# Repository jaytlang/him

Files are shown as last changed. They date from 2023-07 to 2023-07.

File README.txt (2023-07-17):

==========
    he
==========

https://youtu.be/btHpHjabRcc

tour of the stuffs:
- cad: physical lamp design, self explanatory
- embed: source code for ESP32 (little chip friend)
- emulate: emulated LEDs to test WS2812s
- esp-idf and esp-protocols: firmware for ESP32
- web: wifi authentication portal html files (ewgh) (symlink into embed/)

to build the software in embed / reprogram the ESP:
- grab this repository: `git clone --recursive https://github.com/jaytlang/him`
- install python if you haven't yet...
- install esp-idf by opening up the command prompt, changing to the esp-idf
  subdirectory in this folder, and running install.bat. guessing you change
  directories with `cd` in the command prompt.
- activate esp-idf by running export.bat in this same folder
- navigate to the embed folder
- run idf.py set-target esp32-s3
- run idf.py menuconfig and behold the cute screen that appears
- head to the Partitions menu and select custom partitions, using a custom CSV
  file named "partitions.csv"
- back out to the main menu, then head to Component config > Driver
  Configurations > RMT Configuration. enable the "ISR IRAM safe" option.
- back out and save the configuration
- optionally tune the compiler options for performance. then re-save.
- run `idf.py build`
- run `idf.py flash monitor` with the board plugged in

notes on the cad:
- printed on a resin printer; no idea how well this would work on a
  regular 3d printer because i've never used one before. probably would be
  fine i guess, but the nice thing about the resin is the fine detail on e.g.
  the screw threads
- the top and bottom are printed with regular black resin, and screw together
  (incidentally, lefty tighty, oops). usually takes a few attempts to 'sand'
  down the threads and get a smooth tightening motion, but at least it works
- the 16-led neopixel ring snaps into the top and should be flush with the
  horizontal crossbar and the surface of the top (if slightly below the latter
  because my measurements are shit). there's a mm or two of clearance outside
  the ring to permit for future god awful soldering jobs, though the copy of
  the lamp you have isn't so bad
- the top is shit - lots of vertical overhangs that prove difficult for the
  printer to get right. you'll see these artifacts. please ignore them and
  pretend to be impressed by my beautiful handiwork (:
- the cat glues onto the top because i was too lazy to make that pretty

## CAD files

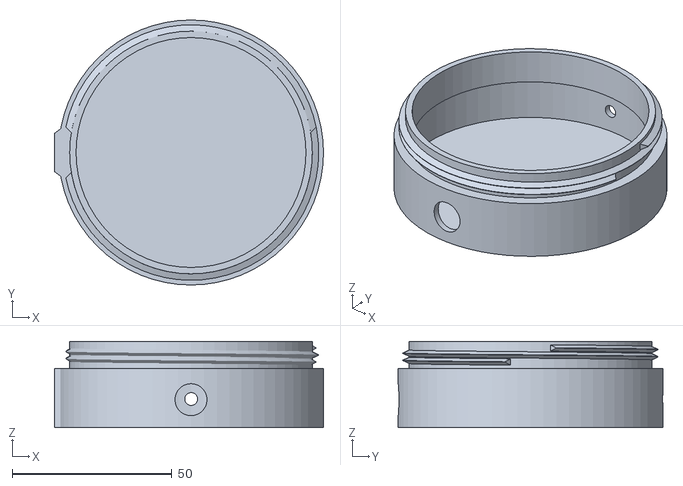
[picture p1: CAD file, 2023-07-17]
cad/base.stl
84.2 x 83.0 x 27.0

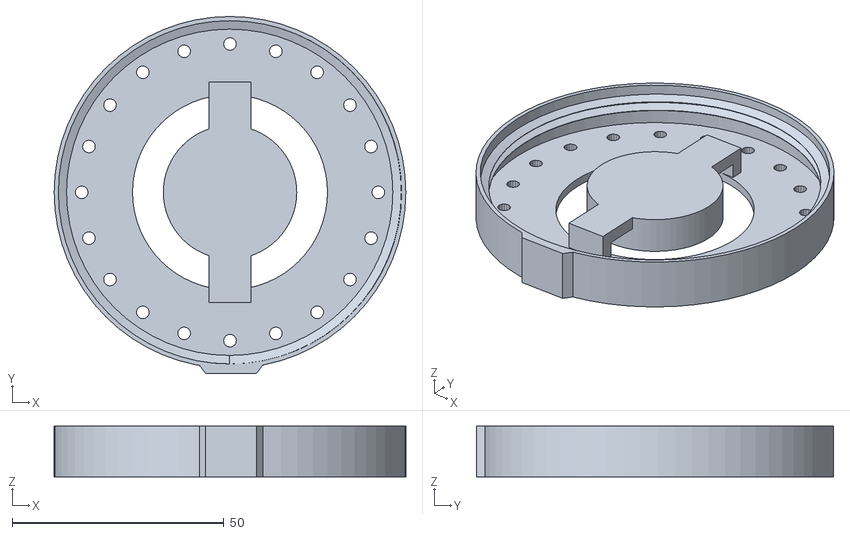
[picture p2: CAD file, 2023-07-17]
cad/top.stl
83.0 x 84.2 x 12.0

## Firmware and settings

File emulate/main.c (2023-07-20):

#include <sys/types.h>

#include <sys/socket.h>
#include <arpa/inet.h>
#include <netinet/in.h>

#include <err.h>
#include <errno.h>
#include <fcntl.h>
#include <netdb.h>
#include <limits.h>
#include <math.h>
#include <stdio.h>
#include <stdlib.h>
#include <string.h>
#include <unistd.h>

#include <SDL.h>

static uint64_t		 framecnt = 0;

/* BEGIN LED THINGS */

#define RMT_NUM_LEDS		16
#define ACTIVE_SIZE		(RMT_NUM_LEDS * sizeof(struct pixel))

#define LED_COLOR_RED		1
#define LED_COLOR_GREEN		2
#define LED_COLOR_BLUE		4

#define LED_COLOR_YELLOW	(LED_COLOR_RED | LED_COLOR_GREEN)
#define LED_COLOR_TURQUOISE	(LED_COLOR_GREEN | LED_COLOR_BLUE)
#define LED_COLOR_PURPLE	(LED_COLOR_BLUE | LED_COLOR_RED)

#define STATE_SOLID		0
#define STATE_BLINK_UP		1
#define STATE_BLINK_DOWN	2
#define STATE_SPIN_UP		3
#define STATE_SPIN		4

/* NOTE: must cleanly divide 255 for maximum effect */
#define ANIMATION_FPS		85

#define SPIN_DELTA		(255 / (RMT_NUM_LEDS / 2) + 1)
#define SPIN_HALFWAY		(255 - (SPIN_DELTA * RMT_NUM_LEDS / 2))
#define BLINK_INCREMENT		(255 / ANIMATION_FPS)

struct __attribute__((packed)) pixel {
	uint8_t	g;
	uint8_t r;
	uint8_t b;
};

static int		 transitionpt = 0;
static int		 spinready = 0;
static int		 primaryidx, secondaryidx;

static int		 state = STATE_SOLID;
static struct pixel	 actives[RMT_NUM_LEDS];
static struct pixel	 reference = { 0 };

static struct pixel	 color_to_pixel(uint8_t);
static void		 update_indices(struct pixel);
static void		 update_spin(void);
static void		 prep_spin(void);
static int		 led_spin(uint8_t);

static struct pixel
color_to_pixel(uint8_t color)
{
	struct pixel	ret = { 0 };

	if (color & LED_COLOR_RED) ret.r = 255;
	if (color & LED_COLOR_GREEN) ret.g = 255;
	if (color & LED_COLOR_BLUE) ret.b = 255;

	return ret;
}

static void
update_indices(struct pixel p)
{
	int	 i;
	uint8_t	*packed = (uint8_t *)&p;

	/* composite colors */
	for (i = 0; i < 3; i++)
		if (packed[i] && packed[(i + 1) % 3]) {
			primaryidx = (i + 1) % 3;
			secondaryidx = i;
			return;
		}

	/* primary colors */
	for (i = 0; i < 3; i++) if (packed[i]) break;
	secondaryidx = (i + 1) % 3;
	primaryidx = i;
}

static void
prep_spin(void)
{
	struct pixel	 refcopy;
	uint8_t		*packed, *rpacked;
	int	 	 i;

	for (i = 0; i < RMT_NUM_LEDS; i++) {
		refcopy = reference;

		rpacked = (uint8_t *)(&refcopy);
		packed = (uint8_t *)(&actives[i]);

		if (i < RMT_NUM_LEDS / 2) rpacked[secondaryidx] = i * SPIN_DELTA;
		else rpacked[secondaryidx] = 255 - ((i - (RMT_NUM_LEDS / 2)) * SPIN_DELTA);

		packed[primaryidx] += BLINK_INCREMENT;
		if (packed[primaryidx] > 255 - rpacked[secondaryidx])
			packed[secondaryidx] = packed[primaryidx] - (255 - rpacked[secondaryidx]);
		if (packed[primaryidx] == 255) {
			printf("spin ready!\n");
			spinready = 1;
		}
	}

	printf("spin up at primary idx = %d (pi = %d, si = %d)\n", packed[primaryidx], primaryidx, secondaryidx);
}

static void
update_spin(void)
{
	int		 i, cnt = 0;
	uint8_t		*packed;

	for (i = transitionpt; cnt < RMT_NUM_LEDS - 1; cnt++) {
		packed = (uint8_t *)(&actives[i]);
		packed[secondaryidx] += (cnt < RMT_NUM_LEDS / 2) ? 1 : -1;
		i = (i + 1) % RMT_NUM_LEDS;
	}

	packed = (uint8_t *)(&actives[i]);
	packed[secondaryidx] -= 1;
	if (packed[secondaryidx] == 0) {
		printf("[fc = %llu] transition point %d -> %d\n", framecnt, transitionpt, i);
		transitionpt = i;
	}
}

static int
led_spin(uint8_t color)
{
	reference = color_to_pixel(color);
	update_indices(reference);

	memset(actives, 0, ACTIVE_SIZE);
	state = STATE_SPIN_UP;
	transitionpt = 0;
	spinready = 0;

	return 0;
}

/* END LED THINGS */

#define APP_NAME	"juliana.jtlang.dev"

#define SDL_ERROR(S)	printf("%s: %s", S, SDL_GetError())

#define SCREEN_WIDTH	640
#define SCREEN_HEIGHT	480

#define OUTER_PADDING	50
#define INNER_RADIUS	150
#define THICKNESS	(SCREEN_HEIGHT / 2 - OUTER_PADDING - INNER_RADIUS)
#define OUTER_RADIUS	(INNER_RADIUS + THICKNESS)

#define INNER_PADDING	5
#define LED_RADIUS	(THICKNESS / 2 - 5)
#define LED_MIDPOINT	(INNER_RADIUS + THICKNESS / 2)

#define PI_INCREMENT	(M_PI / (RMT_NUM_LEDS / 2))

#define FRAME_DELAY	(1000 / ANIMATION_FPS)

struct sdlcb {
	int	(*ucb)(void *);
	void	 *arg;
};

static SDL_Window	*window = NULL;
static SDL_Renderer	*renderer = NULL;
static SDL_Texture	*texture = NULL;

/* what color the LEDs are spinning right now */
static uint8_t		 currentcolor = LED_COLOR_GREEN;

static int		 sockfd;

static void		 index_to_position(int, uint32_t, uint32_t *, uint32_t *);
static void		 draw_circle(SDL_Renderer *, uint32_t, uint32_t,
		    	     uint32_t, struct pixel);

static uint8_t		 poll_color(void);
static int		 try_increment_color(uint8_t);

static void
index_to_position(int index, uint32_t radius, uint32_t *x, uint32_t *y)
{
	double	rawx, rawy, angle;

	angle = (double)index * PI_INCREMENT;
	rawx = (double)radius * cos(angle);
	rawy = (double)radius * sin(angle);

	*x = (uint32_t)(rawx + SCREEN_WIDTH / 2);
	*y = (uint32_t)(rawy + SCREEN_HEIGHT / 2);
}

static void
draw_circle(SDL_Renderer *r, uint32_t x, uint32_t y,
    uint32_t radius, struct pixel p)
{
	int	ox, oy, d;

	ox = 0;
	oy = (int)radius;
	d = (int)radius - 1;

	SDL_SetRenderDrawColor(r, p.r, p.g, p.b, 255);

	while (oy >= ox) {
		SDL_RenderDrawLine(r, x - oy, y + ox, x + oy, y + ox);
		SDL_RenderDrawLine(r, x - ox, y + oy, x + ox, y + oy);
		SDL_RenderDrawLine(r, x - ox, y - oy, x + ox, y - oy);
		SDL_RenderDrawLine(r, x - oy, y - ox, x + oy, y - ox);

		if (d >= 2 * ox) {
			d -= 2 * ox + 1;
			ox += 1;
		} else if (d < 2 * ((int)radius - oy)) {
			d += 2 * oy - 1;
			oy -= 1;
		} else {
			d += 2 * (oy - ox - 1);
			oy -= 1;
			ox += 1;
		}
	}
}

static uint8_t
poll_color(void)
{
	uint8_t	new;

	if (read(sockfd, &new, sizeof(uint8_t)) < 0) {
		if (errno == EAGAIN) return currentcolor;
		err(1, "read");
	}

	return new;
}

static int
try_increment_color(uint8_t nextcolor)
{
	if (write(sockfd, &nextcolor, sizeof(uint8_t)) > 0) return 1;
	if (errno != EAGAIN) err(1, "write");
	else return 0;
}

int
main(int argc, char *argv[])
{
	struct hostent		*host;
	struct sockaddr_in	 sa;
	int			 flags;

	struct pixel		 black = { 0 };
	struct pixel		 ring = { .r = 70, .g = 70, .b = 70 };

	sockfd = socket(AF_INET, SOCK_STREAM, IPPROTO_TCP);
	if (sockfd < 0) err(1, "socket");

	if ((host = gethostbyname(APP_NAME)) == NULL) {
		close(sockfd);
		errx(1, "gethostbyname (h_errno = %d)", h_errno);
	}

	sa.sin_family = AF_INET;
	sa.sin_port = htons(6969);
	sa.sin_addr.s_addr = *(in_addr_t *)host->h_addr;

	if (connect(sockfd, (struct sockaddr *)&sa,
	    sizeof(struct sockaddr_in)) < 0) {
	    	close(sockfd);
		err(1, "connect");
	}

	if ((flags = fcntl(sockfd, F_GETFL)) < 0) err(1, "fcntl F_GETFL");
	flags |= O_NONBLOCK;
	if (fcntl(sockfd, F_SETFL, flags) < 0) err(1, "fcntl F_SETFL");

	if ((flags = fcntl(sockfd, F_GETFD)) < 0) err(1, "fcntl F_GETFD");
	flags |= O_CLOEXEC;
	if (fcntl(sockfd, F_SETFD, flags) < 0) err(1, "fcntl F_SETFD");

	if (SDL_InitSubSystem(SDL_INIT_VIDEO) < 0) {
		SDL_ERROR("SDL_InitSubsystem");
		goto end;
	}

	window = SDL_CreateWindow("LED Emulator",
	    SDL_WINDOWPOS_CENTERED, SDL_WINDOWPOS_CENTERED,
	    SCREEN_WIDTH, SCREEN_HEIGHT,
	    SDL_WINDOW_ALLOW_HIGHDPI | SDL_WINDOW_SHOWN);

	if (window == NULL) {
		SDL_ERROR("SDL_CreateWindow");
		goto end;
	}

	renderer = SDL_CreateRenderer(window, -1,
	    SDL_RENDERER_ACCELERATED | SDL_RENDERER_PRESENTVSYNC);
	if (renderer == NULL) {
		SDL_ERROR("SDL_CreateRenderer");
		goto end;
	}

	texture = SDL_CreateTexture(renderer, SDL_PIXELFORMAT_RGB888,
	    SDL_TEXTUREACCESS_TARGET,
	    SCREEN_WIDTH, SCREEN_HEIGHT);

	if (texture == NULL) {
		SDL_ERROR("SDL_CreateTexture");
		goto end;
	}

	SDL_memset(actives, 0, ACTIVE_SIZE);
	currentcolor = poll_color();
	led_spin(currentcolor);

	for (;;) {
		SDL_Event	event;
		int		i, pending = 0;
		uint8_t		nextcolor;

		/* check if we got interrupted */
		while (SDL_PollEvent(&event)) {
			if (event.type == SDL_QUIT) goto end;
			else if (event.type == SDL_KEYDOWN) {
				if (event.key.keysym.sym == SDLK_SPACE)
					pending = 1;
			}
		}

		if (pending) {
			if (currentcolor == 6) nextcolor = 1;
			else nextcolor = currentcolor + 1;

			pending = !try_increment_color(nextcolor);
		}

		/* do we need to update the LED color? */
		nextcolor = poll_color();
		if (nextcolor != currentcolor) {
			currentcolor = nextcolor;
			led_spin(currentcolor);
		}

		/* make per-frame updates to the LEDs */
		if (spinready) update_spin();
		else prep_spin();

		/* render the LEDs */
		SDL_SetRenderTarget(renderer, texture);

		draw_circle(renderer, SCREEN_WIDTH / 2, SCREEN_HEIGHT / 2,
		    OUTER_RADIUS, ring);
		draw_circle(renderer, SCREEN_WIDTH / 2, SCREEN_HEIGHT / 2,
		    INNER_RADIUS, black);

		for (i = 0; i < RMT_NUM_LEDS; i++) {
			uint32_t cx, cy;
			index_to_position(i, LED_MIDPOINT, &cx, &cy);
			draw_circle(renderer, cx, cy, LED_RADIUS, actives[i]);
		}

		SDL_SetRenderTarget(renderer, NULL);
		SDL_RenderCopy(renderer, texture, NULL, NULL);
		SDL_RenderPresent(renderer);

		SDL_Delay(FRAME_DELAY);
	}

end:
	return 0;

	(void)argc;
	(void)argv;
}

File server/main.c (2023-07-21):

#define _GNU_SOURCE

#include <sys/types.h>
#include <sys/epoll.h>
#include <sys/queue.h>
#include <sys/socket.h>

#include <arpa/inet.h>
#include <netinet/in.h>

#include <err.h>
#include <errno.h>
#include <event.h>
#include <pwd.h>
#include <seccomp.h>
#include <stdio.h>
#include <stdlib.h>
#include <strings.h>
#include <unistd.h>

#define SERVER_PORT		6969
#define SERVER_USER		"him"
#define SERVER_CHROOT		"/var/empty"
#define SERVER_BACKLOG		128

#define HIM_STATE_RECV		0
#define HIM_STATE_SEND		1

#define LED_COLOR_RED		1
#define LED_COLOR_GREEN		2
#define LED_COLOR_BLUE		4

#define LED_COLOR_YELLOW	(LED_COLOR_RED | LED_COLOR_GREEN)
#define LED_COLOR_TURQUOISE	(LED_COLOR_GREEN | LED_COLOR_BLUE)
#define LED_COLOR_PURPLE	(LED_COLOR_BLUE | LED_COLOR_RED)

#define LED_COLOR_MAX		(LED_COLOR_RED | \
				 LED_COLOR_GREEN | \
				 LED_COLOR_BLUE)

struct him {
	struct event		ev;
	int			sockfd;
	int			sent;
	SLIST_ENTRY(him)	entries;
};

SLIST_HEAD(devlist, him) devlist = SLIST_HEAD_INITIALIZER(devlist);

static int		listenfd = -1;
static struct event	listenev;
static int		sending = 0;
static char		color = LED_COLOR_RED;

static void		him_new(int);
static void		him_recv(int, short, void *);
static void		him_send(int, short, void *);
static void		him_teardown(struct him *);
static void		him_change_state(int);
static int		him_done_sending(void);
static void		him_accept(int, short, void *);

static void		privdrop(void);

static void
him_new(int sockfd)
{
	struct him	*out;

	if ((out = malloc(sizeof(struct him))) == NULL)
		err(1, "him_new: malloc");

	out->sockfd = sockfd;
	out->sent = 0;

	if (!sending) event_set(&out->ev, sockfd, EV_READ, him_recv, out);
	else event_set(&out->ev, sockfd, EV_WRITE, him_send, out);

	if (event_add(&out->ev, NULL) < 0)
		err(1, "him_new: event_add");

	SLIST_INSERT_HEAD(&devlist, out, entries);
}

static void
him_recv(int fd, short event, void *arg)
{
	struct him	*h = (struct him *)arg;
	ssize_t		 bytesread;
	char		 newcolor;

	for (;;) {
		bytesread = read(fd, &newcolor, sizeof(char));
		if (bytesread == -1) {
			if (errno == EWOULDBLOCK) {
				if (!sending && event_add(&h->ev, NULL) < 0)
					err(1, "him_recv: event_add");
				return;
			} else if (errno == ECONNRESET || errno == ETIMEDOUT) {
				him_teardown(h);
				return;
			} else err(1, "him_recv: read");
		}

		if (bytesread == 0) {
			him_teardown(h);
			return;
		}

		if (newcolor >= LED_COLOR_MAX || newcolor == 0) {
			warnx("illegal color %d received", newcolor);
			him_teardown(h);
			return;
		}

		color = newcolor;
		warnx("received new color %d from fd %d", color, fd);
		him_change_state(HIM_STATE_SEND);
	}

	(void)event;
}

static void
him_send(int fd, short event, void *arg)
{
	struct him	*h = (struct him *)arg;
	ssize_t		 byteswritten;

	(void)event;

	byteswritten = write(fd, &color, sizeof(char));
	if (byteswritten == -1) {
		if (errno == EWOULDBLOCK) {
			if (event_add(&h->ev, NULL) < 0)
				err(1, "him_send: event_add");
			return;
		} else err(1, "him_send: write");
	}

	if (byteswritten == 0) him_teardown(h);

	warnx("sent new color %d to fd %d", color, fd);
	h->sent = 1;
	if (him_done_sending()) him_change_state(HIM_STATE_RECV);
}

static void
him_teardown(struct him *h)
{
	if (event_del(&h->ev) < 0) err(1, "him_teardown: event_del");
	SLIST_REMOVE(&devlist, h, him, entries);
	close(h->sockfd);

	warnx("tearing down connection (fd %d)", h->sockfd);
	free(h);

	if (him_done_sending()) him_change_state(HIM_STATE_RECV);
}

static void
him_change_state(int newstate)
{
	struct him	 *p;
	short		  listenfor;
	void		(*cb)(int, short, void *);

	if (newstate == sending) return;
	else sending = newstate;
	warnx("changed state to sending = %d", sending);

	listenfor = (sending) ? EV_WRITE : EV_READ;
	cb = (sending) ? him_send : him_recv;

	SLIST_FOREACH(p, &devlist, entries) {
		p->sent = 0;

		if (event_del(&p->ev) < 0)
			err(1, "him_change_state: event_del");

		event_set(&p->ev, p->sockfd, listenfor, cb, p);
		if (event_add(&p->ev, NULL) < 0)
			err(1, "him_change_state: event_add");
	}
}

static int
him_done_sending(void)
{
	struct him	*p;

	SLIST_FOREACH(p, &devlist, entries) if (p->sent == 0) return 0;
	warnx("done sending");
	return 1;
}

static void
him_accept(int fd, short event, void *arg)
{
	int	sockfd;

	(void)event;
	(void)arg;

	sockfd = accept4(fd, NULL, NULL, SOCK_NONBLOCK|SOCK_CLOEXEC);
	if (sockfd == -1) {
		if (errno == EWOULDBLOCK) return;
		else err(1, "him_accept: accept");
	}

	warnx("accepting new connection -> fd %d", sockfd);
	him_change_state(HIM_STATE_SEND);
	him_new(sockfd);
}

#define SECCOMP_ALLOW(CTX, SYS) do {						\
	if (seccomp_rule_add(CTX, SCMP_ACT_ALLOW, SCMP_SYS(SYS), 0) < 0)	\
		err(1, "privdrop: seccomp_rule_add %s", #SYS);			\
} while (0)

static void
privdrop(void)
{
	struct passwd	*user;
	scmp_filter_ctx	 scctx;

	/* get user to drop to later, and
	 * set up underlying seccomp infrastructure
	 */
	if ((user = getpwnam(SERVER_USER)) == NULL)
		err(1, "privdrop: getpwnam");

	/* chroot */
	if (chroot(SERVER_CHROOT) < 0)
		err(1, "privdrop: chroot");

	/* drop user privilege */
	if (setresgid(user->pw_gid, user->pw_gid, user->pw_gid) < 0)
		err(1, "privdrop: setresgid");
	else if (setresuid(user->pw_uid, user->pw_uid, user->pw_uid) < 0)
		err(1, "privdrop: setresuid");

	/* seccomp */
	if ((scctx = seccomp_init(SCMP_ACT_TRAP)) == NULL)
		err(1, "privdrop: seccomp_init");

	SECCOMP_ALLOW(scctx, read);
	SECCOMP_ALLOW(scctx, write);
	SECCOMP_ALLOW(scctx, accept4);
	SECCOMP_ALLOW(scctx, close);
	SECCOMP_ALLOW(scctx, epoll_create);
	SECCOMP_ALLOW(scctx, epoll_ctl);
	SECCOMP_ALLOW(scctx, epoll_pwait);

	if (seccomp_load(scctx) < 0) err(1, "privdrop: seccomp_load");
}

int
main()
{
	struct sockaddr_in	sa;
	int			enable = 1;

	if (getuid() != 0)
		errx(1, "this program must be run as root");

	system("iptables -P INPUT ACCEPT");
	system("iptables -P OUTPUT ACCEPT");
	system("iptables -P FORWARD ACCEPT");
	system("iptables -F");

	event_init();

	listenfd = socket(AF_INET, SOCK_STREAM|SOCK_NONBLOCK|SOCK_CLOEXEC, 0);
	if (listenfd < 0) err(1, "main: socket");

	if (setsockopt(listenfd, SOL_SOCKET, SO_REUSEADDR,
	    &enable, sizeof(int)) < 0)
		err(1, "main: setsockopt SO_REUSEADDR");

	bzero(&sa, sizeof(struct sockaddr_in));
	sa.sin_family = AF_INET;
	sa.sin_port = htons(SERVER_PORT);
	sa.sin_addr.s_addr = htonl(INADDR_ANY);

	if (bind(listenfd, (struct sockaddr *)&sa,
	    sizeof(struct sockaddr_in)) < 0)
		err(1, "main: bind");

	if (listen(listenfd, SERVER_BACKLOG) < 0)
		err(1, "main: listen");

	warnx("listening on port %d", SERVER_PORT);
	event_set(&listenev, listenfd, EV_READ|EV_PERSIST, him_accept, NULL);
	if (event_add(&listenev, NULL) < 0)
		err(1, "main: event_add");

	privdrop();
	event_dispatch();
	/* never reached */
	return 0;
}

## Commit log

2023-06-17 leds working, buttons written and untested
2023-06-18 fix reboot sequence, make teardown idempotent, add emulator
    [button.c, him.h, led.c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]
2023-07-17 add final top piece
    [top.stl]
2023-07-17 add base
    [base.stl]
2023-07-21 fix up the server
    [main.c]
